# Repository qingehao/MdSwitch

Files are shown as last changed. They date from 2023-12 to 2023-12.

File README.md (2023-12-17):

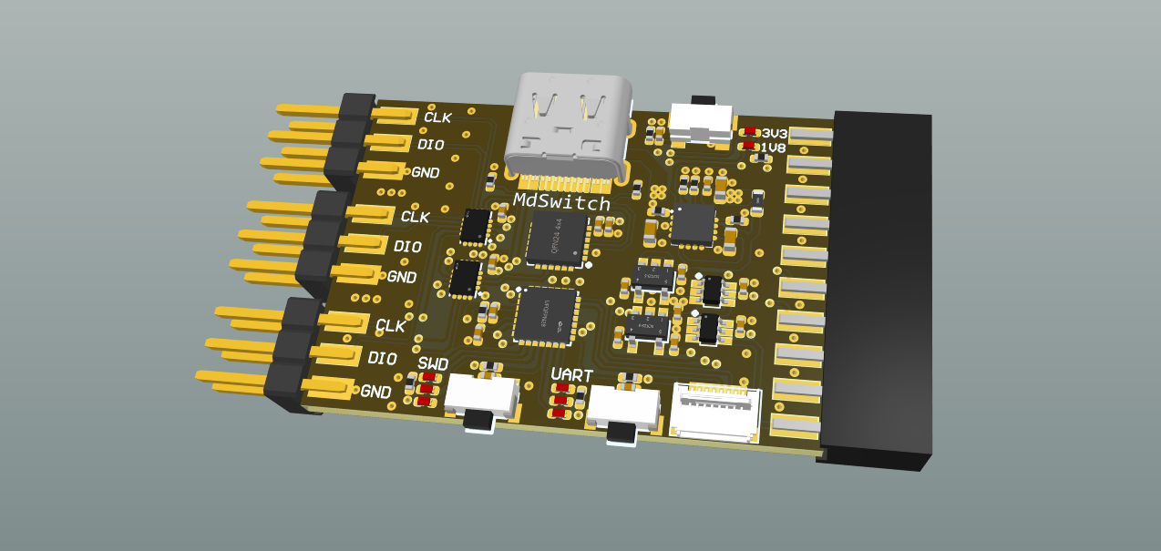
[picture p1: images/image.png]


# MdSwitch

一款方便嵌入式工程师调试的 三路SWD及UART信号多路复用器

### 它有什么作用

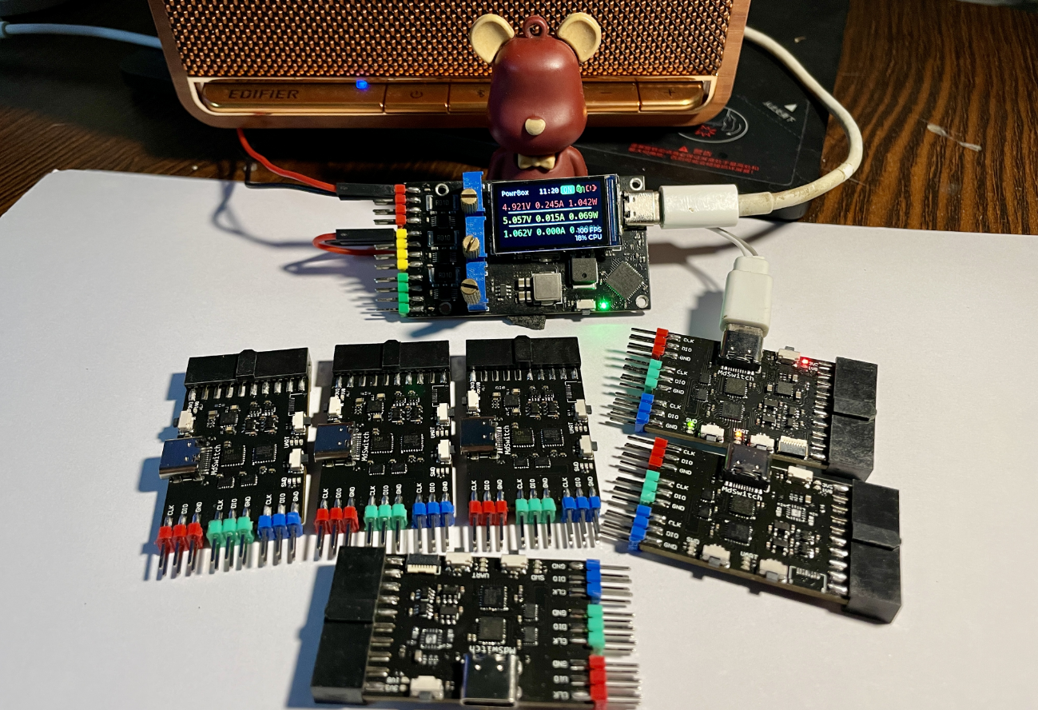
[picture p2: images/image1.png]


平时我们可能会面临着调试多个设备的场景，这种场景下意味着我们需要来回插拔不同设备的SWD或者UART的接线，人工插拔线显得不是那么优雅

MdSwitch旨在为这种场景下提供一种优雅的免人工接线的方案，注意：**其定位只是一个 Switch**。具体功能框图如下：

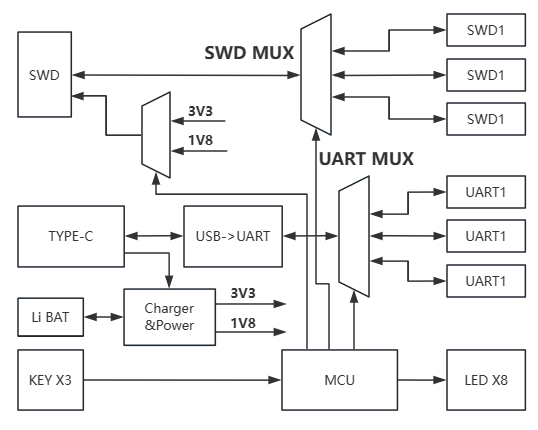
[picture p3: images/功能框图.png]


总的来说，这是我最近为了解决个人痛点设计制作的一个调试辅助设备，最终完成度比较高所以也就顺便开源分享出来了。

> 其中按键处理是基于我之前开源另一个项目MdButton，关联仓库地址在这里：
>
> [qingehao/MdButton (github.com)](https://github.com/qingehao/MdButton)

### 关于信号切换方案

        这是整个设计花时间最多的一个地方，因为我想要保持最终PCB的宽度限制在JLINK的IDC简牛座的宽度范围内，也就是25.4mm。所以限制可供

我选择芯片方案的封装大小。最先想到是4052系列的模拟开关

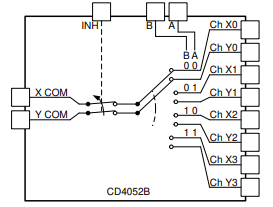
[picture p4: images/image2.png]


但是其支持的信号带宽似乎不足以支持SWD的信号频率，目前市面上JLINK普遍支持的最高是12M~25M的速率。逛了很久的立创商城，发现了一款：

WAS4735Q。最高支持1.2GHz的带宽



##### 关于电池

       关于电池的那一部分，其实是有必要的，JLINK接口的定义，并不向外输出电源，但是板子的工作需要电源，意味着必须额外具备电源供给能力。
诚然，板上的TypeC接口具备供电能力，但是那仍然需要接着一根线，即使我们不需要用到串口。所以便加入了电池，为了具有边冲边用以及即使电池过放也可使用的特性，我选择了一款具备动态电源路径(DPPM)功能的charger芯片, 或者直接使用MOS做一个电源优先级切换电路也可。
但显然DPPM的加入，使得产品好像的电路方案看起来更加合理与优雅，即使成本比较贵。

     另外，电池相关的电路是可以旁路掉的 短接R10，电池相关功能即被禁用，其相关芯片也可不焊接

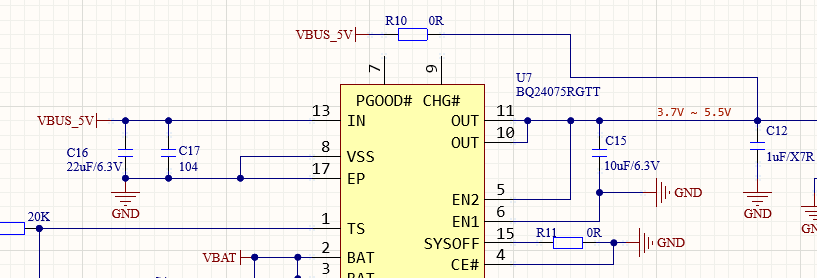
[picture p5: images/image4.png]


##### 其他想起来再说吧~

#### 特别感谢

感谢DJI云台电子小伙伴们的试用，让我知道这玩意确实好用！

#### **最后，喜欢的话可以请我喝杯可乐~**

> 请注意，本项目是**GPL协议**，不支持任何形式的商业产品化（大家可以自行制作）

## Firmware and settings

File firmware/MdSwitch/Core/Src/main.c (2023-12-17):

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
/* Includes ------------------------------------------------------------------*/
#include "main.h"

/* USER CODE BEGIN Includes */
#include "stdint.h"
#include "string.h"
#include "md_button.h"
/* USER CODE END Includes */

UART_HandleTypeDef huart1;

void SystemClock_Config(void);
static void MX_GPIO_Init(void);
static void MX_USART1_UART_Init(void);
/* USER CODE BEGIN 0 */
typedef enum
{
    SWD_BUTTON = 0,
    UART_BUTTON,
		JVREF_BUTTON,
    SW_BUTTON_MAX
} sw_button_t;

static md_button_t sw_button[SW_BUTTON_MAX];

static uint8_t common_btn_read(void *arg)
{
    uint8_t value = 0;

    md_button_t *btn = (md_button_t *)arg;

    switch (btn->id)
    {
      case SWD_BUTTON:
          value = HAL_GPIO_ReadPin(SWD_SW_GPIO_Port, SWD_SW_Pin);
          break;

      case UART_BUTTON:
          value = HAL_GPIO_ReadPin(UART_SW_GPIO_Port, UART_SW_Pin);
          break;

      case JVREF_BUTTON:
          value = HAL_GPIO_ReadPin(JVREF_SW_GPIO_Port, JVREF_SW_Pin);
          break;

      default: break;
    }

    return value;
}

uint8_t key_swd_flag = 0;
uint8_t key_uart_flag = 0;
uint8_t key_jvref_flag = 0;

static void common_btn_evt_cb(void *arg)
{
    md_button_t *btn = (md_button_t *)arg;

    if (btn->id == SWD_BUTTON && btn->event == MD_BTN_CLICK)
    {
      key_swd_flag = 1;
    }
    else if (btn->id == UART_BUTTON && btn->event == MD_BTN_CLICK)
    {
      key_uart_flag = 1;
    }
    else if (btn->id == JVREF_BUTTON && btn->event == MD_BTN_CLICK)
    {
      key_jvref_flag = 1;
    }
}

static void sw_button_init(uint32_t freq)
{
    uint32_t button_cnt = 0;
    memset(&sw_button[0], 0x0, sizeof(sw_button));
  
    md_button_set_scan_freq(freq);

    for (int i = 0; i < SW_BUTTON_MAX; i ++)
    {
        sw_button[i].usr_button_read = common_btn_read;
        sw_button[i].cb = common_btn_evt_cb;
        sw_button[i].active_level = 0;
        sw_button[i].short_press_duration = md_button_ms2cnt(800);
        sw_button[i].long_press_duration = md_button_ms2cnt(3000);
        sw_button[i].max_multiple_clicks_interval = md_button_ms2cnt(200);
        button_cnt = md_button_add(&sw_button[i]);
    }
}

#define INDEX_NONE 0
void uart_sel_ch(uint8_t index)
{
  uint8_t a0 = 1;
  uint8_t a1 = 1;
  uint8_t led1 = 1;
  uint8_t led2 = 1;
  uint8_t led3 = 1;

  switch(index)
  {
    case 0: break;
    case 1: 
    {
      a0 = 1; a1 = 0;
      led1 = 0;
    } break;

    case 2: 
    {
      a0 = 0; a1 = 1;
      led2 = 0;
    } break;

    case 3: 
    {
      a0 = 0; a1 = 0;
      led3 = 0;
    } break;

    default: break;
  }
  HAL_GPIO_WritePin(LED_UART1_GPIO_Port, LED_UART1_Pin, led1);
  HAL_GPIO_WritePin(LED_UART2_GPIO_Port, LED_UART2_Pin, led2);
  HAL_GPIO_WritePin(LED_UART3_GPIO_Port, LED_UART3_Pin, led3);
  HAL_GPIO_WritePin(UART_SW_A0_GPIO_Port, UART_SW_A0_Pin, a0);
  HAL_GPIO_WritePin(UART_SW_A1_GPIO_Port, UART_SW_A1_Pin, a1);
}

void swd_sel_ch(uint8_t index)
{
  uint8_t a0 = 1;
  uint8_t a1 = 1;
  uint8_t led1 = 1;
  uint8_t led2 = 1;
  uint8_t led3 = 1;

  switch(index)
  {
    case 0: break;
    case 1: 
    {
      a0 = 1; a1 = 1;
      led1 = 0;
    } break;

    case 2: 
    {
      a0 = 1; a1 = 0;
      led2 = 0;
    } break;

    case 3: 
    {
      a0 = 0; a1 = 1;
      led3 = 0;
    } break;

    default: break;
  }
  HAL_GPIO_WritePin(LED_SWD1_GPIO_Port, LED_SWD1_Pin, led1);
  HAL_GPIO_WritePin(LED_SWD2_GPIO_Port, LED_SWD2_Pin, led2);
  HAL_GPIO_WritePin(LED_SWD3_GPIO_Port, LED_SWD3_Pin, led3);
  HAL_GPIO_WritePin(SWD_SW_A0_GPIO_Port, SWD_SW_A0_Pin, a0);
  HAL_GPIO_WritePin(SWD_SW_A1_GPIO_Port, SWD_SW_A1_Pin, a1);
}

void jvref_sel_ch(uint8_t index)
{
  /**
   * 0 -- none
   * 1 -- 3v3
   * 2 -- 1v8
   * 3 -- none
   */
  switch(index)
  {
    case 0:
    case 3:
    {
      HAL_GPIO_WritePin(JVREF_EN_GPIO_Port, JVREF_EN_Pin, 0);
      HAL_GPIO_WritePin(LED_JVREF_1V8_GPIO_Port, LED_JVREF_1V8_Pin, 1);
      HAL_GPIO_WritePin(LED_JVREF_3V3_GPIO_Port, LED_JVREF_3V3_Pin, 1);
    } break;

    case 2:
    {
      HAL_GPIO_WritePin(JVREF_EN_GPIO_Port, JVREF_EN_Pin, 1);
			HAL_GPIO_WritePin(JVREF_SEL_GPIO_Port,  JVREF_SEL_Pin, 1);
      HAL_GPIO_WritePin(LED_JVREF_1V8_GPIO_Port, LED_JVREF_1V8_Pin, 0);
      HAL_GPIO_WritePin(LED_JVREF_3V3_GPIO_Port, LED_JVREF_3V3_Pin, 1);
    } break;
    case 1:
    {
      HAL_GPIO_WritePin(JVREF_EN_GPIO_Port, JVREF_EN_Pin, 1);
      HAL_GPIO_WritePin(JVREF_SEL_GPIO_Port, JVREF_SEL_Pin, 0);
      HAL_GPIO_WritePin(LED_JVREF_1V8_GPIO_Port, LED_JVREF_1V8_Pin, 1);
      HAL_GPIO_WritePin(LED_JVREF_3V3_GPIO_Port, LED_JVREF_3V3_Pin, 0);
    } break;
  }
}
void jlink_switcher_init(void)
{
  uart_sel_ch(INDEX_NONE);
  swd_sel_ch(INDEX_NONE);
	jvref_sel_ch(INDEX_NONE);
  sw_button_init(100);
}
static uint8_t uart_index = 0;
static uint8_t swd_index = 0;
static uint8_t jvref_index[4] = {0};

void jlink_switcher_process(void)
{
  static uint32_t last_tick = 0;
  uint32_t now_tick = HAL_GetTick();
  if (now_tick - last_tick >= 10)
  {
    last_tick = now_tick;
    md_button_scan();
  }

  if (key_swd_flag == 1)
  {
    key_swd_flag = 0;
    swd_index ++;
    if (swd_index > 3) {
      swd_index = 1;
    }
  }

  if (key_uart_flag == 1)
  {
    key_uart_flag = 0;
    uart_index ++;
    if (uart_index > 3) {
      uart_index = 1;
    }
  }

  if (key_jvref_flag == 1)
  {
    key_jvref_flag = 0;

    jvref_index[swd_index]++;
    
    if (jvref_index[swd_index] > 3) {
      jvref_index[swd_index] = 1;
    }
  }

  uart_sel_ch(uart_index);
  swd_sel_ch(swd_index);
  if (swd_index != INDEX_NONE)
  {
    jvref_sel_ch(jvref_index[swd_index]);
  }
}
/* USER CODE END 0 */

/**
  * @brief  The application entry point.
  * @retval int
  */
int main(void)
{
  /* MCU Configuration--------------------------------------------------------*/

  /* Reset of all peripherals, Initializes the Flash interface and the Systick. */
  HAL_Init();

  /* Configure the system clock */
  SystemClock_Config();

  /* Initialize all configured peripherals */
  MX_GPIO_Init();
  MX_USART1_UART_Init();
  /* USER CODE BEGIN 2 */
	jlink_switcher_init();
  /* USER CODE END 2 */

  /* Infinite loop */
  /* USER CODE BEGIN WHILE */
  while (1)
  {
    /* USER CODE END WHILE */
		jlink_switcher_process();
    /* USER CODE BEGIN 3 */
  }
  /* USER CODE END 3 */
}

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


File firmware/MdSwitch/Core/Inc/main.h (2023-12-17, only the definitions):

#define SWD_SW_A0_Pin GPIO_PIN_14
#define SWD_SW_A0_GPIO_Port GPIOC
#define SWD_SW_A1_Pin GPIO_PIN_15
#define SWD_SW_A1_GPIO_Port GPIOC
#define UART_SW_A0_Pin GPIO_PIN_0
#define UART_SW_A0_GPIO_Port GPIOA
#define UART_SW_A1_Pin GPIO_PIN_1
#define UART_SW_A1_GPIO_Port GPIOA
#define LED_SWD1_Pin GPIO_PIN_2
#define LED_SWD1_GPIO_Port GPIOA
#define LED_SWD2_Pin GPIO_PIN_3
#define LED_SWD2_GPIO_Port GPIOA
#define LED_SWD3_Pin GPIO_PIN_4
#define LED_SWD3_GPIO_Port GPIOA
#define SWD_SW_Pin GPIO_PIN_5
#define SWD_SW_GPIO_Port GPIOA
#define LED_UART3_Pin GPIO_PIN_6
#define LED_UART3_GPIO_Port GPIOA
#define LED_UART2_Pin GPIO_PIN_7
#define LED_UART2_GPIO_Port GPIOA
#define LED_UART1_Pin GPIO_PIN_0
#define LED_UART1_GPIO_Port GPIOB
#define UART_SW_Pin GPIO_PIN_1
#define UART_SW_GPIO_Port GPIOB
#define JVREF_EN_Pin GPIO_PIN_8
#define JVREF_EN_GPIO_Port GPIOA
#define JVREF_SEL_Pin GPIO_PIN_6
#define JVREF_SEL_GPIO_Port GPIOC
#define LED_JVREF_1V8_Pin GPIO_PIN_15
#define LED_JVREF_1V8_GPIO_Port GPIOA
#define LED_JVREF_3V3_Pin GPIO_PIN_3
#define LED_JVREF_3V3_GPIO_Port GPIOB
#define JVREF_SW_Pin GPIO_PIN_5
#define JVREF_SW_GPIO_Port GPIOB

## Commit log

2023-12-17 Init repo.
    [JlinkSwitch.PrjPcb, JlinkSwitch.SchDoc]
2023-12-17 ENH: readme图片改为相对路径

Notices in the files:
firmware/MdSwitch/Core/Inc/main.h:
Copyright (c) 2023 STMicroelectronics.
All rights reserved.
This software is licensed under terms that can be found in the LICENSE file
